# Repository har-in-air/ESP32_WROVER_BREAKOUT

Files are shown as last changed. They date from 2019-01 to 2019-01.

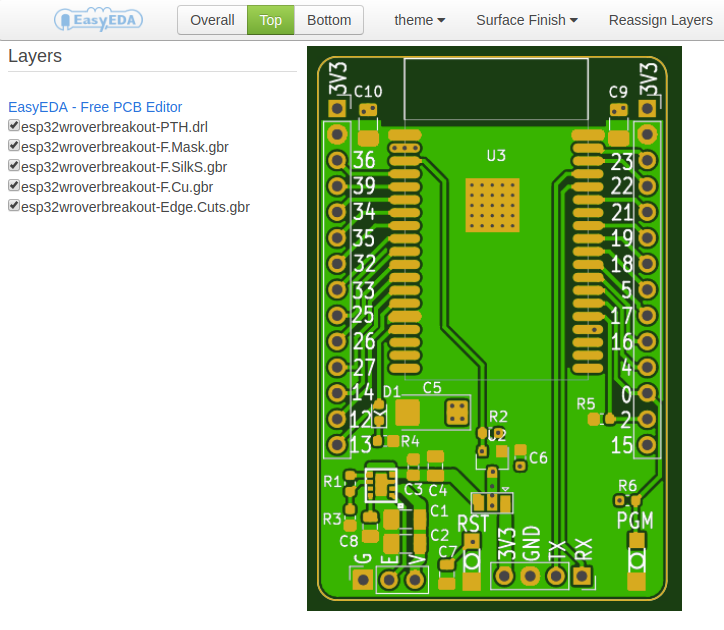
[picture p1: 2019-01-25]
esp32_wrover_breakout_top.png

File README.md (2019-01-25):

# ESP32_WROVER_BREAKOUT

## Features
* Breadboard compatible connector spacing
* TPS82140  switched-mode power supply - Vinmax 17V, Vout 3.3V @ max 2A, Iq ~20uA 
* TPS3839 voltage supervisor keeps ESP32 in reset if supply voltage drops below threshold. This is useful when you have a large capacitor on the 3.3V power supply that discharges slowly. Use TPS3839K33DBZ for a voltage threshold of ~2.93V.
* Solder jumper to select between external regulated 3.3V supply or TPS82140 output.
* Schematic and board layout using Kicad 5.0.2 on Ubuntu 18.10 amdx64
* Gerber files generated using instructions at https://support.jlcpcb.com/article/44-how-to-export-kicad-pcb-to-gerber-files
* PCB layout designed for hand soldering
  * vias in pads, no thermal relief on pads. 
  * Use low-temperature solder for TPS82140, this will make it easier and safer to reflow with a DIY process, e.g. electric skillet. 
  * There's no need to risk damage to the ESP32-WROVER module by reflow-soldering it. Just apply thermal grease (not solder paste) on the ESP32-WROVER ground pad before soldering the castellated-edge pins.

## Credits
ESP32-WROVER footprint and component library from https://github.com/aliafshar/esp32-wrover-kicad

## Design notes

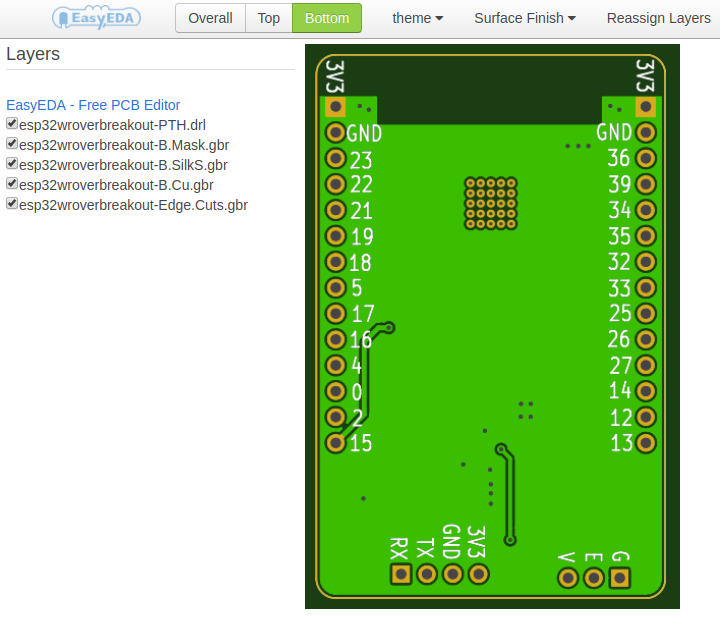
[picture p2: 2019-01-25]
esp32_wrover_breakout_bottom.png

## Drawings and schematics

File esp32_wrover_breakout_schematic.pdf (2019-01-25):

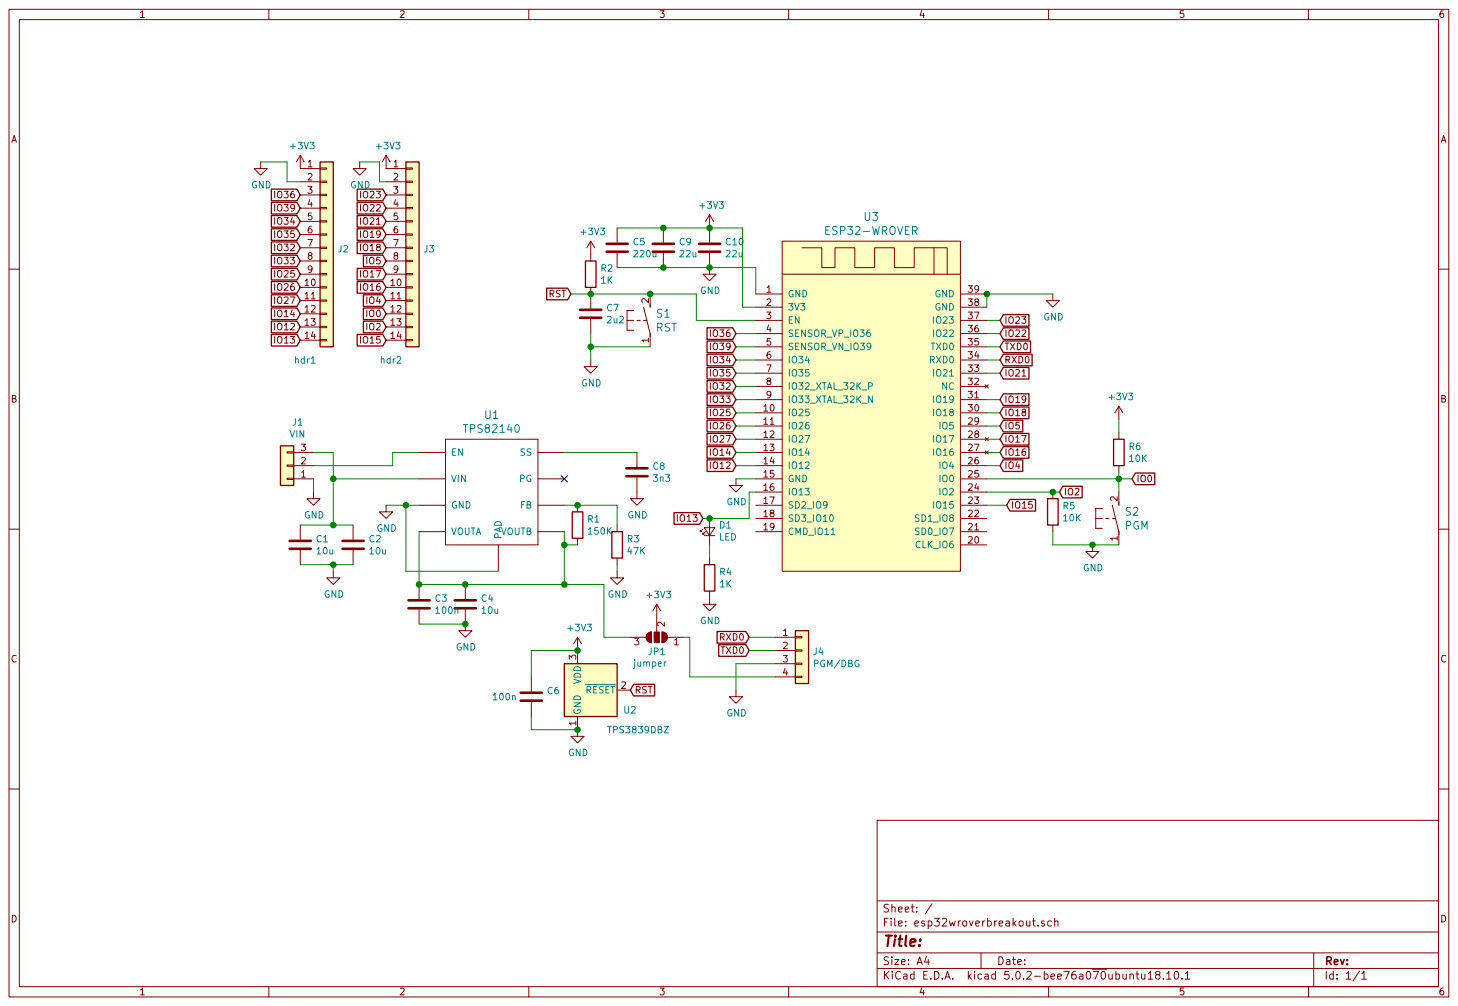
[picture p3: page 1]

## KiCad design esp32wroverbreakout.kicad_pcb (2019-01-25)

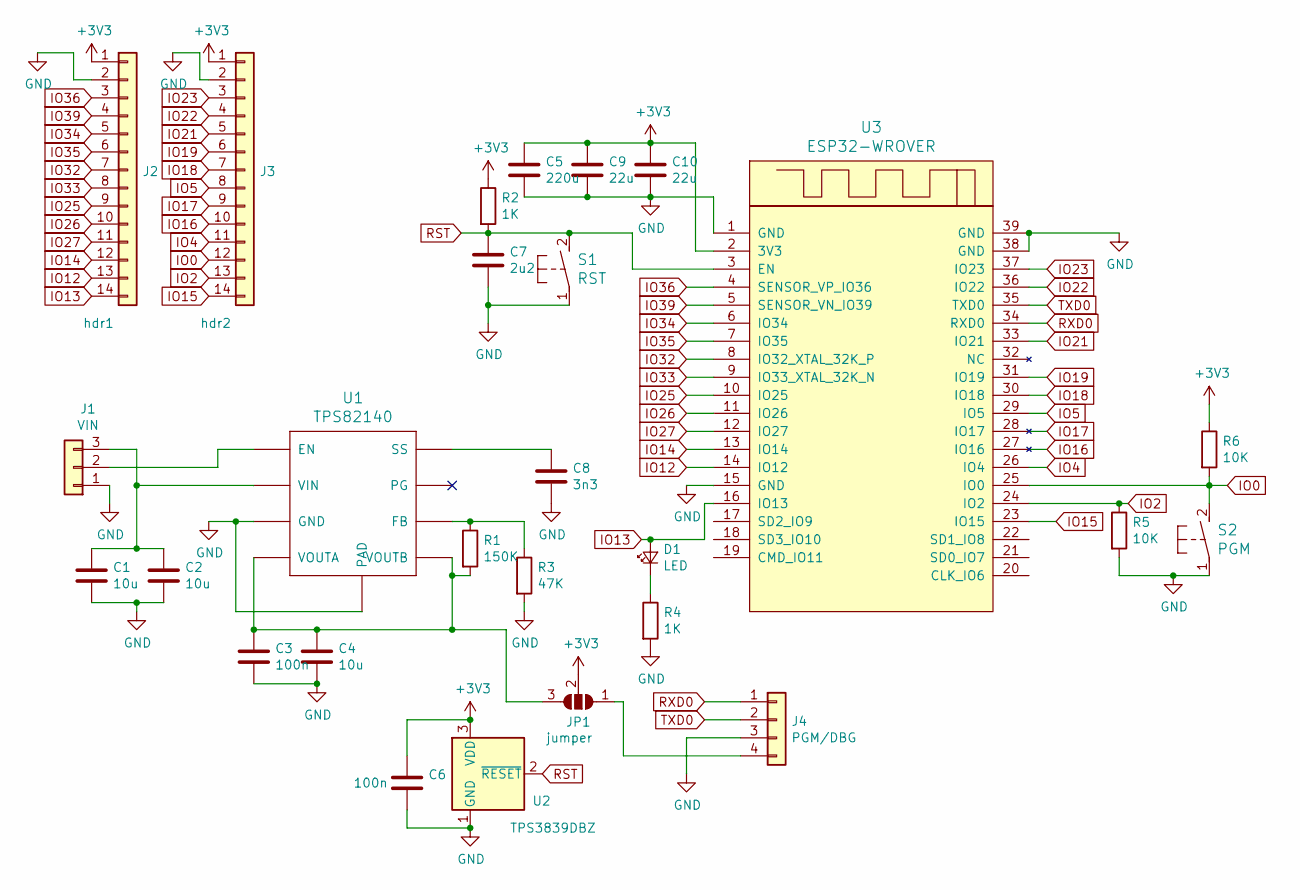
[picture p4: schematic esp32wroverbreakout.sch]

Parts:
C1, C2: 10u; C_1206_3216Metric
C3, C6: 100n; C_0603_1608Metric
C4: 10u; C_0805_2012Metric
C5: 220u; CP_EIA-6032-28_Kemet-C
C7: 2u2; C_0805_2012Metric
C8: 3n3; C_0805_2012Metric
C9, C10: 22u; C_1206_3216Metric
D1: LED; LED_0603_1608Metric
J1: VIN; PinSocket_1x03_P2.54mm_Vertical
J2: hdr1; PinSocket_1x14_P2.54mm_Vertical
J3: hdr2; PinSocket_1x14_P2.54mm_Vertical
J4: PGM/DBG; PinSocket_1x04_P2.54mm_Vertical
JP1: jumper; SolderJumper-3_P1.3mm_Open_Pad1.0x1.5mm
R1: 150K; R_0603_1608Metric
R2, R4: 1K; R_0603_1608Metric
R3: 47K; R_0603_1608Metric
R5, R6: 10K; R_0603_1608Metric
S1: RST; DTSM-3
S2: PGM; DTSM-3
U1: TPS82140
U2: TPS3839DBZ; SOT-23
U3: ESP32-WROVER

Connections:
+3V3: C5.1, C6.1, C9.1, C10.1, J2.1, J3.1, JP1.2 (C), R2.1, R6.1, U2.3 (VDD), U3.2 (3V3)
GND: C1.2, C2.2, C3.2, C4.2, C5.2, C6.2, C7.2, C8.2, C9.2, C10.2, J1.1, J2.2, J3.2, J4.3, R3.2, R4.2, R5.2, S1.1, S2.1, U1.P$3 (GND), U1.P$9 (PAD), U2.1 (GND), U3.1 (GND), U3.15 (GND), U3.38 (GND), U3.39 (GND)
IO0: J3.12, R6.2, S2.2, U3.25 (IO0)
IO2: J3.13, R5.1, U3.24 (IO2)
IO4: J3.11, U3.26 (IO4)
IO5: J3.8, U3.29 (IO5)
IO12: J2.13, U3.14 (IO12)
IO13: D1.2 (A), J2.14, U3.16 (IO13)
IO14: J2.12, U3.13 (IO14)
IO15: J3.14, U3.23 (IO15)
IO16: J3.10, U3.27 (IO16)
IO17: J3.9, U3.28 (IO17)
IO18: J3.7, U3.30 (IO18)
IO19: J3.6, U3.31 (IO19)
IO21: J3.5, U3.33 (IO21)
IO22: J3.4, U3.36 (IO22)
IO23: J3.3, U3.37 (IO23)
IO25: J2.9, U3.10 (IO25)
IO26: J2.10, U3.11 (IO26)
IO27: J2.11, U3.12 (IO27)
IO32: J2.7, U3.8 (IO32_XTAL_32K_P)
IO33: J2.8, U3.9 (IO33_XTAL_32K_N)
IO34: J2.5, U3.6 (IO34)
IO35: J2.6, U3.7 (IO35)
IO36: J2.3, U3.4 (SENSOR_VP_IO36)
IO39: J2.4, U3.5 (SENSOR_VN_IO39)
unnamed: C1.1, C2.1, J1.3, U1.P$2 (VIN)
unnamed: C3.1, C4.1, JP1.3 (B), R1.2, U1.P$4 (VOUTA), U1.P$5 (VOUTB)
unnamed: C8.1, U1.P$8 (SS)
unnamed: D1.1 (K), R4.1
unnamed: J1.2, U1.P$1 (EN)
unnamed: J4.4, JP1.1 (A)
unnamed: R1.1, R3.1, U1.P$6 (FB)
RST: C7.1, R2.2, S1.2, U2.2 (~RESET), U3.3 (EN)
RXD0: J4.1, U3.34 (RXD0)
TXD0: J4.2, U3.35 (TXD0)

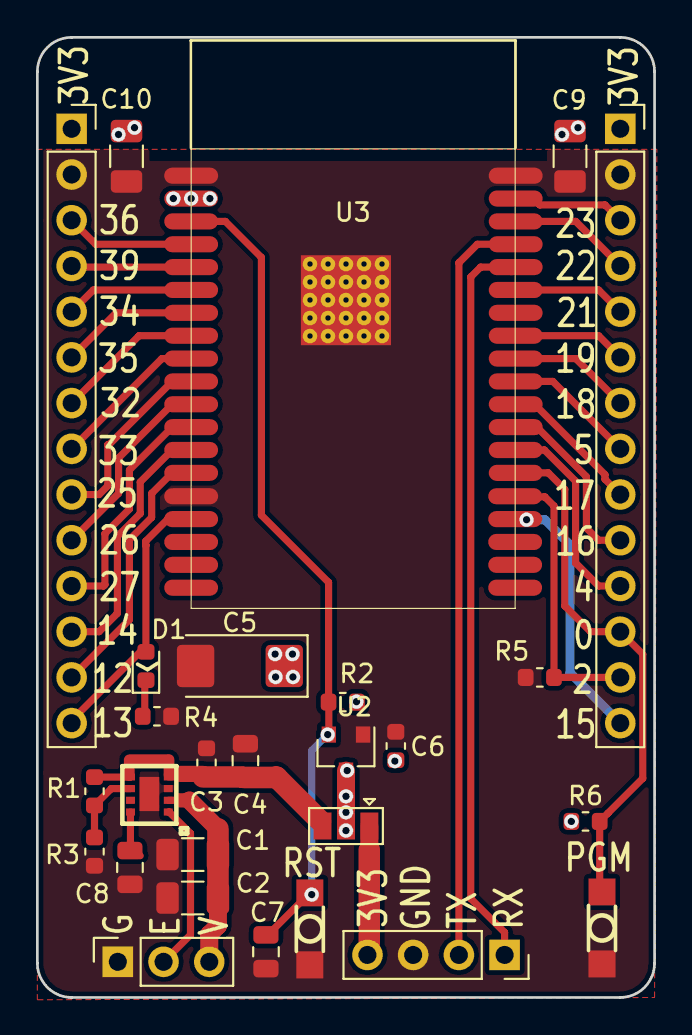
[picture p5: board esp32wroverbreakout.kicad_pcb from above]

Board: 2 copper layers, 34.3 x 53.3 mm, 27 parts (0 on the bottom side), 36 nets.

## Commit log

2019-01-25 Add files via upload
    Gerber zip file
2019-01-25 Add files via upload
    Kicad 5.0 project, schematic and board files
    [esp32wroverbreakout.kicad_pcb, esp32wroverbreakout.sch]
2019-01-25 Add files via upload
    EasyEDA generated views of PCB top and bottom
